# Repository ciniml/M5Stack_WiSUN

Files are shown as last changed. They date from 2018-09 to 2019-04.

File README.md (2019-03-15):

# M5Stack用 Wi-SUN拡張モジュール

## 概要

M5StackにロームのWi-SUNモジュール BP35A1 をつなぐための拡張モジュールの設計データ

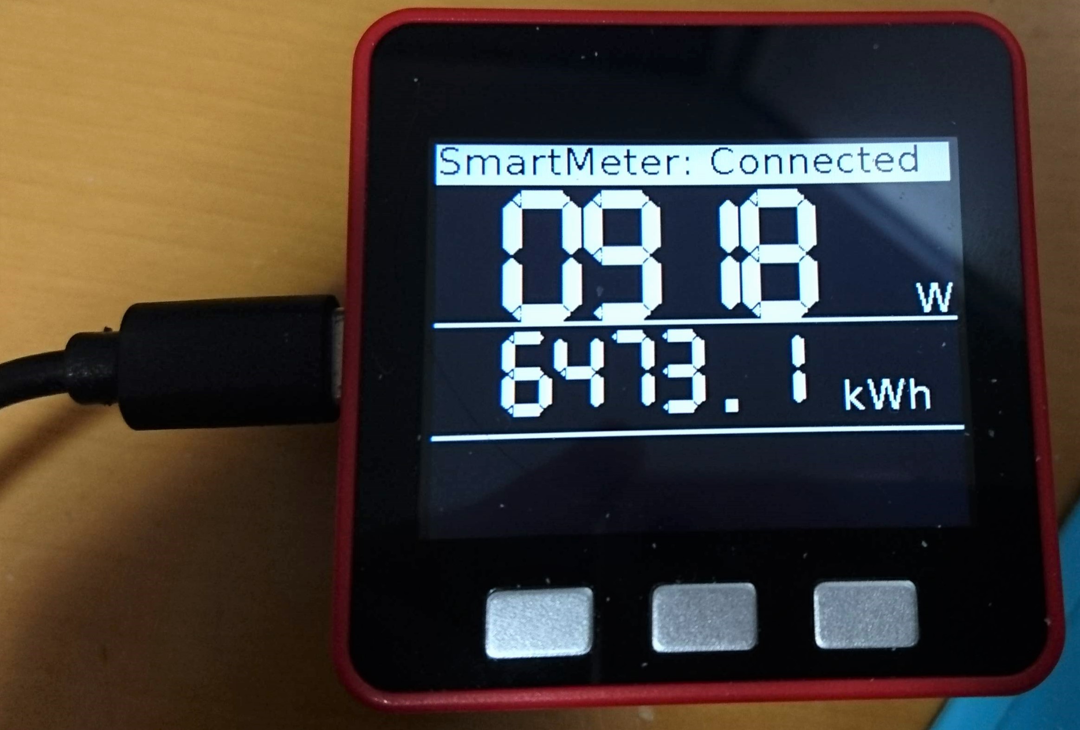
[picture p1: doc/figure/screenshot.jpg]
動作画面


* [動画](https://youtu.be/MU2Bb5bknPw)

## ファームウェア

* ビルド済みのカスタムMicroPythonバイナリと、pythonディレクトリに入っているスクリプトを含むSPIFFSイメージを書き込むように設定したM5BurnerをOneDriveに置いてあるので適当に使ってください。

https://1drv.ms/f/s!AvgeuJrD0ORom7oEdzDq509qd-Dngg

* M5Stackの公式にM5Burnerの再配布の許可をもらおうとTwitterでmentionを送ったら、公式の方に含めていただけることになりましたので、公式M5BurnerにあるWiSUNというファームを書き込むのでも良いです。

### 機能

* スマートメーターから瞬時電力、瞬時電流、積算電力量を取得してM5Stackの画面に簡易表示
* SORACOM Inventory + SORACOM Harvestを使って上記データを収集・可視化

### 使い方

1. ファームウェアを書き込んだあと、USBケーブルをPCにつないだままでTeraTermなどのターミナルでM5Stackのシリアルポートを開きます。
2. リセットがかかって、そのうち `Input SSID:` とプロンプトが表示されますので、接続先Wi-FiアクセスポイントのSSIDを入力してEnterを押します。
3. 次に `Input Password:` と表示されますのでWi-Fi接続のパスワードを入力します。 (*で隠されたりしないので、覗き見られないように注意してください。)
4. そのまましばらくすると M5StackのIPアドレスを表示したのち、`appconfig` が無いというエラーで停止し、 REPLの状態になります。
5. M5Stackの同一ネットワークにいるPCからWinSCPなどの`FTP`クライアント機能で (4)に表示されたアドレスに接続します。ユーザー名とパスワードは両方とも `esp32` です。
6. FTP経由でのファイル転送が可能になりますので、appconfig.pyという名前で以下の内容のファイルを作って M5Stackの `/flash` 以下にアップロードします。

```python
wifi_ssid = 'Wi-FiのSSID'
wifi_password = 'Wi-Fiのパスワード'
route_b_id = 'Route BのID (電力会社から教えてもらうやつ)'
route_b_password = 'Route Bのパスワード (電力会社から教えてもらうやつ)'
inventory_id = 'SORACOM InventoryのデバイスID'
inventory_password = 'SORACOM Inventoryのデバイス用パスワード'
```

7. M5Stackのリセットボタンを押してリセットします。

## (書きかけ)

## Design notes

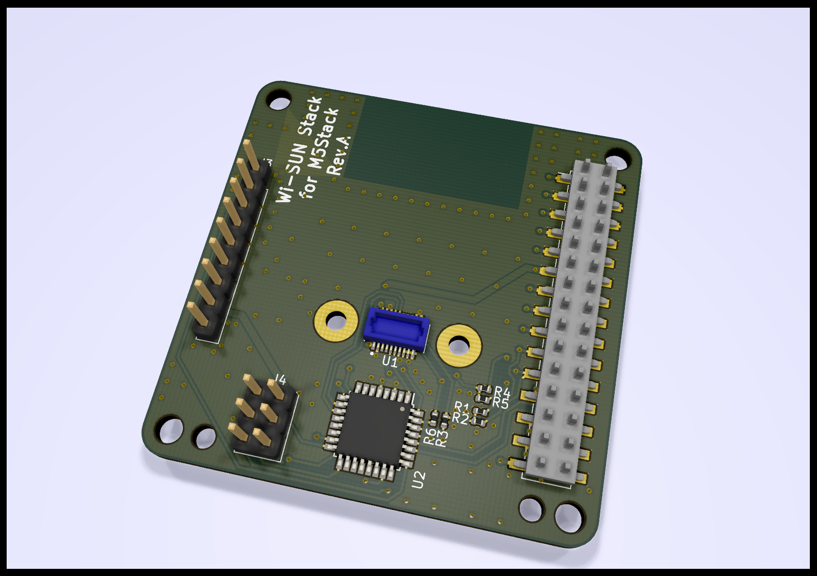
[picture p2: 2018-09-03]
M5Stack_WiSUN.png

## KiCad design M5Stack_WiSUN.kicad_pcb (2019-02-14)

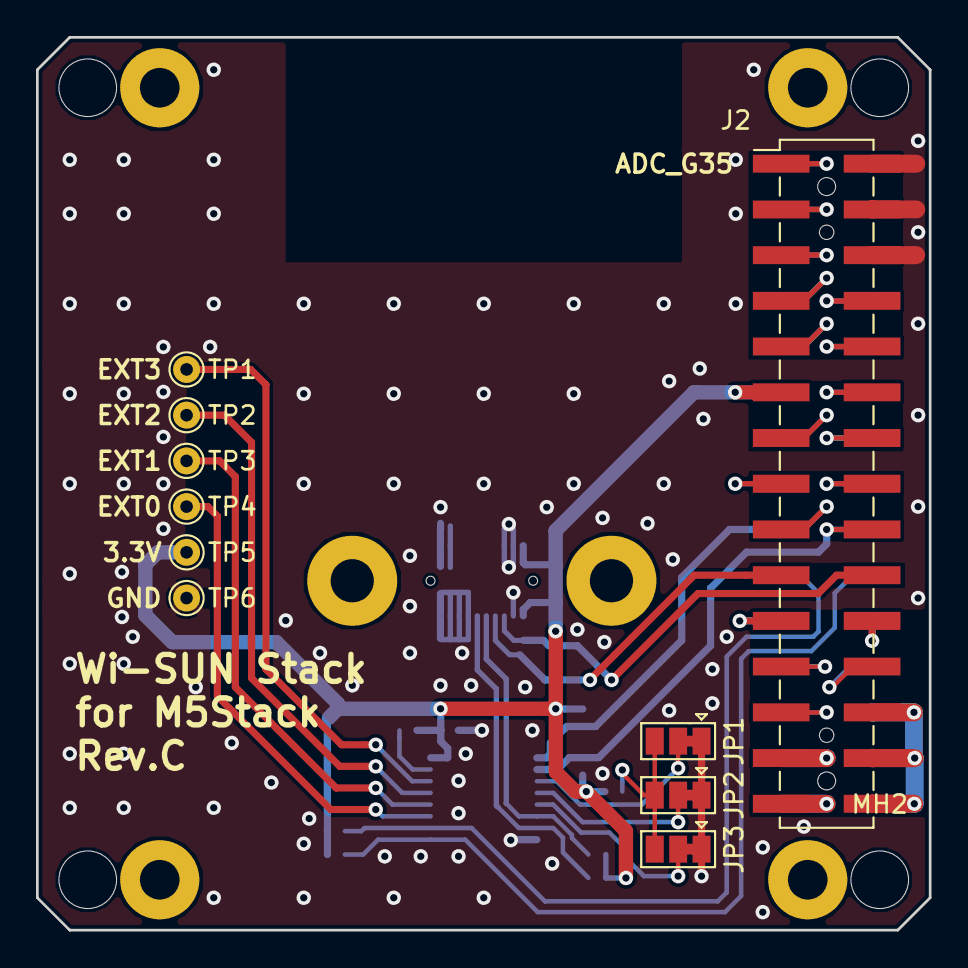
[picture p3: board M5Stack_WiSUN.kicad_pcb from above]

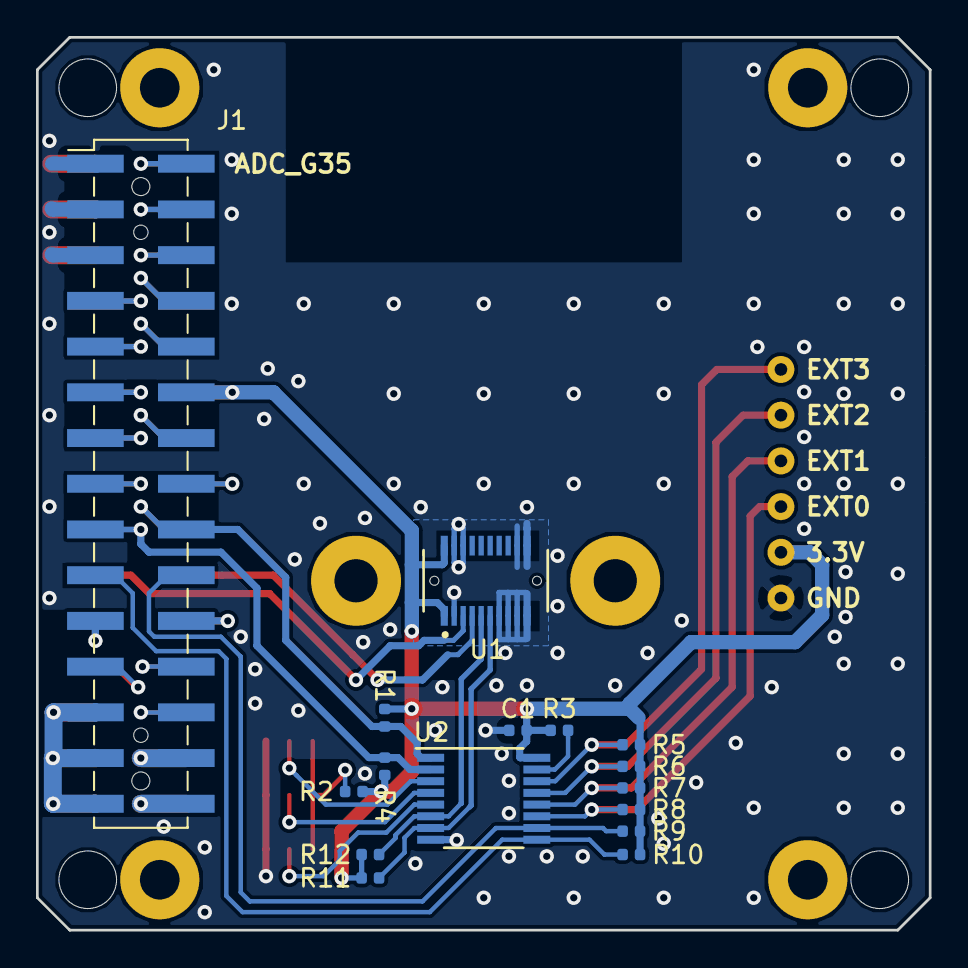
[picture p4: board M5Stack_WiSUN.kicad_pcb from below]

Board: 2 copper layers, 49.6 x 49.6 mm, 34 parts (16 on the bottom side), 39 nets.

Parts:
C1: 100n; C_0402_1005Metric
J1: MBUS_BOTTOM; MBUS_Socket
J2: MBUS_TOP; MBUS_Header
JP1, JP2, JP3: Jumper_3_Bridged12; SolderJumper-3_P1.3mm_Bridged12_Pad1.0x1.5mm
MH1, MH2, MH3, MH4: Corner; MountingHole_3.2mm_M3
MH5, MH6, MH7, MH8: Fix; MountingHole_2.2mm_M2_Pad
R1, R2, R3, R4: 2k; R_0402_1005Metric
R5, R6, R7, R8, R9, R10, R11, R12: 100k; R_0402_1005Metric
TP1, TP2, TP3, TP4, TP5, TP6: TestPoint; TestPoint_THTPad_D1.5mm_Drill0.7mm
U1: BP35A1
U2: PCA9557; TSSOP-16_4.4x5mm_P0.65mm

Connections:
+3V3: C1.1, J1.12, J2.11, R1.1, R2.1, R3.2, R4.1, R5.1, R6.1, R7.1, R8.1, R9.1, R10.1, R11.1, R12.1, TP5.1, U1.1, U1.11, U2.16
+5V: J1.28, J2.27
/A0: JP1.2, U2.3
/A1: JP2.2, U2.4
/A2: JP3.2, U2.5
/ADC_G35: J1.2, J2.1
/ADC_G36: J1.4, J2.3
/BATTERY: J1.30, J2.29
/BP35_RESET: R11.2, U1.6, U2.7
/BP35_WKUP: R12.2, U1.5, U2.6
/DAC: J1.10, J2.9
/DAC_SPK: J1.8, J2.7
/EXT0: R8.2, TP4.1, U2.11
/EXT1: R7.2, TP3.1, U2.12
/EXT2: R6.2, TP2.1, U2.13
/EXT3: R5.2, TP1.1, U2.14
/GPIO_G2: J2.20, U1.3
/GPIO_G2_R: J1.19, R10.2, U2.9
/GPIO_G5: J2.19, U1.4
/GPIO_G5_R: J1.20, R9.2, U2.10
/HPWR: J1.25, J1.27, J1.29, J2.26, J2.28, J2.30
/IIS_IN: J1.26, J2.25
/IIS_MK: J1.24, J2.23
/IIS_OUT: J1.23, J2.24
/IIS_SK: J1.21, J2.22
/IIS_WS: J1.22, J2.21
/MISO: J1.9, J2.10
/MOSI: J1.7, J2.8
/RST: J1.6, J2.5
/RXD0: J1.13, J2.14
/RXD2: J1.15, J2.16
/SCK: J1.11, J2.12
/SCL: J1.18, J2.17, R1.2, U2.1
/SDA: J1.17, J2.18, R4.2, U2.2
/TXD0: J1.14, J2.13
/TXD2: J1.16, J2.15
GND: C1.2, J1.1, J1.3, J1.5, J2.2, J2.4, J2.6, JP1.1, JP2.1, JP3.1, TP6.1, U1.2, U1.7, U1.8, U1.9, U1.10, U1.12, U1.13, U1.19, U1.20, U2.8
unnamed: JP1.3, JP2.3, JP3.3, R2.2
unnamed: R3.1, U2.15

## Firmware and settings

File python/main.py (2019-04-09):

"""
Main module for M5Stack-WiSUN Expansion board sample application.
License: Boost Software License
"""
try:
    from mpy_builtins import machine, const
    from typing import Tuple, Callable, List, Dict, Optional, Union, Generator, Optional
except:
    from m5stack import lcd
    import machine
    import network
    import time
    from machine import reset
    from urequests import request, Response
    import _thread

import gc
import logging
import uasyncio as asyncio
from bp35 import BP35A1
import struct
import appconfig
from ioexpander import IOExpander

def reset(): 
    machine.reset()

# Configure logger.
logging.basicConfig(logging.DEBUG)
log = logging.Logger('MAIN')

# Synchronize time
rtc = machine.RTC()
rtc.ntp_sync(server='ntp.jst.mfeed.ad.jp',tz='JST')

# Configure IOExpander
i2c_scl = machine.Pin(22)
i2c_sda = machine.Pin(21)
i2c = machine.I2C(scl=i2c_scl, sda=i2c_sda)
ioe = IOExpander(i2c=i2c, address=24, output=0x03, inversion=0x00, direction=0xfc)

# Initialize BP35A1 interfaces
#bp35_wkup  = machine.Pin(12, machine.Pin.OUT)
#bp35_reset = machine.Pin(13, machine.Pin.OUT)
bp35_wkup = ioe.pin(0)
bp35_reset = ioe.pin(1)
bp35_uart = machine.UART(1, rx=2, tx=5, baudrate=115200, lineend='\r\n')

bp35 = BP35A1(uart=bp35_uart, wkup=bp35_wkup, reset=bp35_reset)

bp35_state = ''

class EchonetLiteFrame(object):
    ESV_SETI_SNA   = 0x50
    ESV_SETC_SNA   = 0x51
    ESV_GET_SNA    = 0x52
    ESV_INF_SNA    = 0x53
    ESV_SETGET_SNA = 0x5e    
    ESV_SETI       = 0x60
    ESV_SETC       = 0x61
    ESV_GET        = 0x62
    ESV_INF_REQ    = 0x63
    ESV_SETGET     = 0x6e
    ESV_SET_RES    = 0x71
    ESV_GET_RES    = 0x72
    ESV_INF        = 0x73
    ESV_INFC       = 0x74
    ESV_INFC_RES   = 0x7a
    ESV_SETGET_RES = 0x7e

    def __init__(self, buffer):
        if not isinstance(buffer, memoryview):
            self._m = memoryview(buffer)
        else:
            self._m = buffer # type: memoryview
        self._next_offset = 12
    
    def is_valid(self) -> bool:
        if self._m is None or len(self._m) < 4:
            return False
        # Check EHD
        if not (self._m[0] == 0x10 and self._m[1] == 0x81):
            return False
        return True
    
    def init(self) -> None:
        self._m[0] = 0x10
        self._m[1] = 0x81

    def tid(self, value:Optional[int]=None)->int:
        if value is not None:
            self._m[2] = value >> 8
            self._m[3] = value & 0xff
        return (self._m[2] << 8) | self._m[3]
    def seoj(self, value:Optional[bytes]=None)->memoryview:
        if value is not None:
            self._m[4:4+3] = value
        return self._m[4:4+3]
    def deoj(self, value:Optional[bytes]=None)->memoryview:
        if value is not None:
            self._m[7:7+3] = value
        return self._m[7:7+3]
    def esv(self, value:Optional[int]=None)->int:
        if value is not None:
            self._m[10] = value
        return self._m[10]
    def opc(self, value:Optional[int]=None)->int:
        if value is not None:
            self._m[11] = value
        return self._m[11]
    
    def target_properies(self)->Generator[memoryview, None, None]:
        opc = self.opc()
        offset = 12
        for i in range(opc):
            if offset + 1 >= len(self._m):
                break
            pdc = self._m[offset + 1]
            if offset + 2 + pdc >= len(self._m):
                break
            yield self._m[offset:offset + 2 + pdc]
            offset += 2 + pdc
    
    def clear_properties(self)->None:
        self.opc(0)
        self._next_offset = 12
    
    def add_property(self, epc:int, data:Optional[bytes])->None:
        self._m[self._next_offset + 0] = epc
        data_len = len(data) if data is not None else 0
        self._m[self._next_offset + 1] = data_len
        if data_len > 0:
            self._m[self._next_offset + 2:self._next_offset + 2 + data_len] = data
        self._next_offset += 2 + data_len
        self.opc(self.opc() + 1)

    def get_length(self) -> int: 
        return self._next_offset
    
    def bytes(self)->memoryview:
        return self._m[:self._next_offset+1]

PROPERTY_COEFFICIENT      = const(0xd3) # 係数
PROPERTY_CUMULATIVE_VALUE = const(0xe0) # 積算電力量計測値
PROPERTY_CUMULATIVE_UNIT  = const(0xe1) # 積算電力量単位
PROPERTY_INSTANT_POWER    = const(0xe7) # 瞬時電力計測値
PROPERTY_INSTANT_CURRENT  = const(0xe8) # 瞬時電流計測値

# Construct ECHONETlite request frame
getPropertyFrame = EchonetLiteFrame(bytearray(64))
getPropertyFrame.init()
getPropertyFrame.tid(0x0000)            # TID = 0x0000
getPropertyFrame.seoj(b'\x05\xff\x01')  # SEOJ 送信元EOJ クラスグループ=管理・操作関連機器, クラス=コントローラ
getPropertyFrame.deoj(b'\x02\x88\x01')  # DEOJ 送信先EOJ クラスグループ=住宅・設備関連機器, クラス=低圧スマート電力量メータ
getPropertyFrame.esv(EchonetLiteFrame.ESV_GET)  # プロパティ読み出し要求
getPropertyFrame.add_property(PROPERTY_COEFFICIENT     , None)   
getPropertyFrame.add_property(PROPERTY_CUMULATIVE_VALUE, None)   
getPropertyFrame.add_property(PROPERTY_CUMULATIVE_UNIT , None)   
getPropertyFrame.add_property(PROPERTY_INSTANT_POWER   , None)   
getPropertyFrame.add_property(PROPERTY_INSTANT_CURRENT , None)   


def post_json(endpoint:str, json:str) -> bool:
    try:
        r = request('POST', endpoint, data=json, headers={'Content-Type':'application/json'}) # type:Response
        r.close()
        return 200 <= r.status_code and r.status_code < 300
    except:
        log.error('Failed to post data to PowerBI')
        return False

last_instant_power = None
last_instant_current = None
last_cumulative_power = None
async def main_task():
    global bp35_state
    global last_instant_power,last_instant_current,last_cumulative_power
    
    while True:
        bp35_state = 'Initializing'
        gc.collect()
        if not await bp35.reset():
            log.error('Failed to reset the Wi-SUN module.')
            bp35_state = 'Error'
            await asyncio.sleep(1)
            continue
        
        if not await bp35.set_password(appconfig.route_b_password, timeout=5000):
            log.error('Failed to set password.')
            continue
        if not await bp35.set_route_b_id(appconfig.route_b_id, timeout=5000):
            log.error('Failed to set route-b ID.')
            continue

        while True:
            gc.collect()
            bp35_state = 'Scanning'
            log.info("Scanning PANs...")
            success, pans = await bp35.scan(0xffffffff, 6, timeout=1000, scan_timeout=30000)
            if success:
                log.info("PANs detected: {0}".format(pans))
                break
            else:
                log.error("Failed to scan PANs")

        if len(pans) == 0:
            continue
        
        ## Connecting
        gc.collect()
        bp35_state = 'Connecting'
        pan = pans[0] # type: Dict[bytes, bytes]
        if not (b'Channel' in pan and b'Pan ID' in pan and b'Addr' in pan):
            log.error("Invalid PAN information")
            continue

        channel     = int(str(pan[b'Channel'], 'utf-8'), 16)
        pan_id      = str(pan[b'Pan ID'], 'utf-8')
        mac_address = str(pan[b'Addr'], 'utf-8')
        
        if not await bp35.set_channel(channel, timeout=1000):
            log.error("Failed to set channel.")
            continue
        if not await bp35.set_pan_id(pan_id, timeout=1000):
            log.error("Failed to set PAN ID")
            continue
        ll_address = await bp35.get_link_local_address(mac_address, timeout=1000)
        if ll_address is None:
            log.error("Failed to get link local address")
            continue
        
        gc.collect()
        if not await bp35.connect_to(ll_address, timeout=10000):
            log.error("Failed to connect to the coordinator.")
            continue
        
        gc.collect()
        bp35_state = 'Connected'
        response_buffer = bytearray(1024)
        prev_last_instant_power = 0.0
        no_post_count = 0
        no_response_count = 0
        no_response_reset_count = 0
        harvest_endpoint = 'https://api.soracom.io/v1/devices/{0}/publish?device_secret={1}'.format(appconfig.inventory_id, appconfig.inventory_password)
        while True:
            if await bp35.send_to(True, ll_address, 0xe1a, getPropertyFrame.bytes(), timeout=10000):
                response = await bp35.receive(response_buffer, timeout=10000)
                if response is None:
                    no_response_count += 1
                    if no_response_count >= 6: # 6回連続でレスポンスが無かったらリセットする。
                        log.info("No response. Perform reset.")
                        no_response_reset_count += 1
                        break
                else:
                    no_response_count = 0
                    frame = EchonetLiteFrame(response)
                    if frame.is_valid():
                        seoj = frame.seoj()
                        esv  = frame.esv()
                        
                        coefficient = 1
                        cumulative_unit = 1.0
                        cumulative_value = None

                        log.debug("seoj={0}, esv={1}".format(seoj, esv))
                        if seoj == b'\x02\x88\x01' and esv == EchonetLiteFrame.ESV_GET_RES: # レスポンスはプロパティ読み取り要求の応答?
                            for mv in frame.target_properies():
                                if mv[0] == PROPERTY_INSTANT_POWER and mv[1] == 4 and len(mv) == 6:   # 瞬時電力量
                                    power = struct.unpack('>i', mv[2:])[0]
                                    log.info('Power={0}[W]'.format(power))
                                    last_instant_power = power
                                elif mv[0] == PROPERTY_INSTANT_CURRENT and mv[1] == 4 and len(mv) == 6:   # 瞬時電流
                                    current_r, current_t = struct.unpack('>hh', mv[2:])
                                    log.info('Current R={0},T={1}[dA]'.format(current_r, current_t))
                                    last_instant_current = (current_r, current_t)
                                elif mv[0] == PROPERTY_COEFFICIENT and mv[1] == 4 and len(mv) == 6: # 係数
                                    coefficient = struct.unpack('>I', mv[2:])[0]
                                    log.debug('Coefficient={0}'.format(coefficient))
                                elif mv[0] == PROPERTY_CUMULATIVE_UNIT and mv[1] == 1 and len(mv) == 3: # 単位
                                    unit = mv[2]
                                    if unit == 0x00:
                                        cumulative_unit = 1.0e0
                                    elif unit == 0x01:
                                        cumulative_unit = 1.0e-1
                                    elif unit == 0x02:
                                        cumulative_unit = 1.0e-2
                                    elif unit == 0x03:
                                        cumulative_unit = 1.0e-3
                                    elif unit == 0x04:
                                        cumulative_unit = 1.0e-4
                                    elif unit == 0x0a:
                                        cumulative_unit = 1.0e+1
                                    elif unit == 0x0b:
                                        cumulative_unit = 1.0e+2
                                    elif unit == 0x0c:
                                        cumulative_unit = 1.0e+3
                                    elif unit == 0x0d:
                                        cumulative_unit = 1.0e+4
                                    log.debug('CumulativeUnit={0}'.format(cumulative_unit))
                                elif mv[0] == PROPERTY_CUMULATIVE_VALUE and mv[1] == 4 and len(mv) == 6: # 積算電力量
                                    cumulative_value = struct.unpack('>I', mv[2:])[0]
                                    log.debug('CumulativeValue={0}'.format(cumulative_value))
                            
                            if cumulative_value is not None:
                                last_cumulative_power = cumulative_value*cumulative_unit*coefficient
                                log.info('Cumulative Power={0}[kWh]'.format(last_cumulative_power))
                            
                            if last_instant_power is not None:
                                prev_last_instant_power = 1 if prev_last_instant_power < 1 else prev_last_instant_power
                                diff_percent = abs(last_instant_power - prev_last_instant_power) / prev_last_instant_power
                                if diff_percent < 0.1:
                                    no_post_count += 1
                                
                                if diff_percent >= 0.1 or no_post_count >= 30:
                                    prev_last_instant_power = last_instant_power
                                    timestamp = time.strftime('%Y-%m-%dT%H:%M:%S.000Z')
                                    log.info("POST: instant={0},cumulative={1},diff={2},no_post={3}".format(last_instant_power, last_cumulative_power, diff_percent, no_post_count))
                                    json = '{{"power":{0},"cumul":{1},"reset":{2},"timestamp":"{3}"}}'.format(last_instant_power, last_cumulative_power, no_response_reset_count, timestamp)
                                    log.debug(json)
                                    post_json(appconfig.powerbi_url, '[' + json + ']')
                                    post_json(harvest_endpoint, json)
                                    no_post_count = 0
                            
                            await asyncio.sleep(10)

# asyncio.set_debug(True)
# asyncio.core.set_debug(True)

lcd.clear()
async def display_task():
    while True:
        lcd.font(lcd.FONT_DejaVu24)
        fw, fh = lcd.fontSize()

        lcd.setTextColor(color=lcd.BLACK, bcolor=lcd.WHITE)
        lcd.text(0, 0, 'SmartMeter: ' + bp35_state + '\r')
        lcd.rect(0, fh, 320, 2, 0, 0)
        
        lcd.setTextColor(color=lcd.WHITE, bcolor=lcd.BLACK)
        lcd.text(319-fw*1, 90, 'W')
        lcd.text(319-fw*3, 150, 'kWh')

        lcd.font(lcd.FONT_7seg, transparent=False, dist=25, width=5, outline=False)
        sfw, sfh = lcd.fontSize()

        if last_instant_power is not None:
            if last_instant_power >= 1500:
                lcd.setTextColor(color=lcd.RED)
            else:
                lcd.setTextColor(color=lcd.WHITE)
            lcd.text(40, fh+4, '{0:04d}'.format(last_instant_power))
        else:
            lcd.setTextColor(color=lcd.WHITE)
            lcd.text(40, fh+4, '----')
        
        lcd.setTextColor(color=lcd.WHITE)
        lcd.rect(0, fh+sfh+4, 320, 2, 0xffffff, 0xffffff)
        lcd.font(lcd.FONT_7seg, transparent=False, dist=15, width=3, outline=False)
        
        if last_cumulative_power is not None:
            lcd.text(40, fh+sfh+10, '{0:06.1f}'.format(last_cumulative_power))
        else:
            lcd.text(40, fh+sfh+10, '------')

        lcd.rect(0, 180, 320, 2, 0xffffff, 0xffffff)

        # if last_instant_current is not None:
        #     lcd.text(0, font_size[1]*3, 'Current: R={0},T={1}[A]'.format(last_instant_current[0]/10,last_instant_current[1]/10))
        
        gc.collect()
        await asyncio.sleep_ms(100)



log.info(gc.mem_alloc())
gc.collect()
log.info(gc.mem_alloc())

def main_task_runner():
    while True:
        pass
    #loop = asyncio.EventLoop()
    #loop.create_task(main_task())
    #loop.run_forever()

#tid = _thread.start_new_thread('hoge', main_task_runner, ())

loop = asyncio.get_event_loop()
loop.create_task(display_task())
loop.create_task(main_task())
loop.run_forever()

    

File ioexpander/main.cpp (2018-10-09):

/*
 * ioexpander.cpp
 *
 * Author : Kenta IDA
 */ 

#include <avr/io.h>
#include <avr/interrupt.h>
#include <stdint.h>
#include <avr/sleep.h>

#define DEFINE_PORT_DEF(port) \
struct Port##port { \
	static inline void set_port_bit(uint8_t bit) { PORT##port |= _BV(bit); } \
	static inline void clear_port_bit(uint8_t bit) { PORT##port &= ~_BV(bit); } \
	static inline void set_ddr_bit(uint8_t bit) { DDR##port |= _BV(bit); } \
	static inline void clear_ddr_bit(uint8_t bit) { DDR##port &= ~_BV(bit); } \
	static inline uint8_t read_port() { return PORT##port; } \
	static inline uint8_t read_ddr() { return DDR##port; } \
	static inline uint8_t read_pin() { return PIN##port; } \
};

//DEFINE_PORT_DEF(A)
DEFINE_PORT_DEF(B)
DEFINE_PORT_DEF(C)
DEFINE_PORT_DEF(D)

template<typename portdef, uint8_t bit>
struct Pin 
{

	static inline void as_output(bool initial) 
	{ 
		if( initial ) {
			portdef::set_port_bit(bit);
			} else {
			portdef::clear_port_bit(bit);
		}
		portdef::set_ddr_bit(bit);
	}
	static inline void as_input(bool pullup) 
	{ 
		portdef::clear_ddr_bit(bit); 
		if( pullup ) {
			portdef::set_port_bit(bit);
		} else {
			portdef::clear_port_bit(bit);
		}
	}
	static inline void output(bool value) 
	{
		if( value ) {
			portdef::set_port_bit(bit);
		} else {
			portdef::clear_port_bit(bit);
		}
	}
	static inline bool input() 
	{
		return (portdef::read_pin() & _BV(bit)) != 0;
	}
};

typedef Pin<PortD, 7> PIN_BP35_RTS;
typedef Pin<PortD, 6> PIN_BP35_CTS;
typedef Pin<PortD, 5> PIN_PD5;
typedef Pin<PortD, 4> PIN_PD4;
typedef Pin<PortD, 3> PIN_BP35_RESET;
typedef Pin<PortD, 2> PIN_BP35_WKUP;
typedef Pin<PortD, 1> PIN_TXD0;
typedef Pin<PortD, 0> PIN_RXD0;

typedef Pin<PortC, 5> PIN_SCL;
typedef Pin<PortC, 4> PIN_SDA;

struct I2CRegisterData 
{
	uint8_t signature;
	uint8_t moduleInputs;
	uint8_t moduleOutputs;
	uint8_t reserved;
};
static volatile I2CRegisterData i2cRegisters = {
	0xa5,
	0x00,
	0x00,
};
static const uint8_t i2cRegisterWriteMasks[sizeof(I2CRegisterData)] = {
	0x00,
	0x00,
	0xff,
	0x00,
};

static volatile uint8_t* i2cRegisterHead = reinterpret_cast<volatile uint8_t*>(&i2cRegisters);
static const uint8_t i2cRegisterSize = sizeof(I2CRegisterData);
static volatile bool i2cRegisterUpdated = false;

ISR(TWI0_vect) 
{
	static uint8_t registerAddress = 0;
	static bool addressRecognized = false;
	
	switch(TWSR0 & 0xf8) {
		case 0xA8:	// Own SLA+R
		case 0xB8:	// DATA transmitted, ACK returned
			if(addressRecognized && registerAddress < i2cRegisterSize ) {
				TWDR0 = *(i2cRegisterHead + registerAddress);
				++registerAddress;
			} else {
				TWDR0 = 0;	
			}
			break;
		case 0x60:	// Own SLA+W
			addressRecognized = false;
			break;
		case 0x80:	// DATA received, ACK returned
		case 0x88:	// DATA received, NACK returned
			if( !addressRecognized ) {
				addressRecognized = true;
				registerAddress = TWDR0;
			} else {
				if( registerAddress < i2cRegisterSize ) {
					uint8_t mask = *(i2cRegisterWriteMasks + registerAddress);
					uint8_t value = *(i2cRegisterHead + registerAddress);
					*(i2cRegisterHead + registerAddress) = (value & ~mask) | (TWDR0 & mask);
					i2cRegisterUpdated = true;
					++registerAddress;
				}
			}
			TWCR0 |= _BV(TWEA);
			break;
		case 0xA0: // STOP or RS condition
			TWCR0 |= _BV(TWEA);
			break;
		case 0x00:	// BUS ERROR
			TWCR0 |= _BV(TWEA) | _BV(TWSTO);
			break;
		default:
			TWCR0 |= _BV(TWEA);
			break;
		
	}
	TWCR0 |= _BV(TWINT);	// Clear interrupt flag.
}

static void twiInitialize(uint8_t address) 
{
	TWCR0 = 0;
	
	TWSR0 = 0;
	TWBR0 = F_CPU / (100*1000UL);
	TWAR0 = address << 1;
	TWAMR0 = 0;
	
	TWCR0 = _BV(TWEA) | _BV(TWEN) | _BV(TWIE);	
}

int main(void)
{
	PIN_RXD0::as_input(true);
	PIN_TXD0::as_input(true);
	PIN_BP35_WKUP::as_output(false);
	PIN_BP35_RESET::as_output(false);
	PIN_PD4::as_input(true);
	PIN_PD5::as_input(true);
	PIN_BP35_CTS::as_input(true);
	PIN_BP35_RTS::as_output(true);
	
	// Enable I2C bus pull-up
	PIN_SDA::as_input(true);
	PIN_SCL::as_input(true);
	
	// Initialize TWI
	twiInitialize(0x64);
	
	sei();
	set_sleep_mode( SLEEP_MODE_IDLE );
    while (1) 
    {
		sleep_enable();
		sei();
		sleep_cpu();
		sleep_disable();
		cli();
		
		if( i2cRegisterUpdated ) {
			i2cRegisterUpdated = false;
			uint8_t output = i2cRegisters.moduleOutputs;
			PIN_BP35_WKUP::output(output & 1);
			PIN_BP35_RESET::output(output & 2);
			PIN_BP35_RTS::output(output & 4);
		}
		{
			uint8_t input = 0;
			input |= PIN_BP35_CTS::input() ? 0 : 1;
			i2cRegisters.moduleInputs = input;
		}
		
    }
}

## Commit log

2018-10-09 Implement BP35 driver and EchonetLiteFrame
2018-10-27 PCB revision B
    [M5Stack_WiSUN.gbl, M5Stack_WiSUN.gbo, M5Stack_WiSUN.gbp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]
2018-10-27 Change BP35A1 module to support Rev.B PCB (no longer supports Rev.A PCB)
    [bp35.py, main.py]
2019-01-05 Move BP35A1 to bottom side. Use I2C IO expander to control BP35A1 reset and wake pins.
    [M5Stack_WiSUN.kicad_pcb, M5Stack_WiSUN.sch]
2019-01-20 Revision C
    [M5Stack_WiSUN.gbl, M5Stack_WiSUN.gbo, M5Stack_WiSUN.gbp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]
2019-02-14 Update to support rev.C board
2019-02-14 Update enclosure
2019-10-29 Add UI Flow modulesX
